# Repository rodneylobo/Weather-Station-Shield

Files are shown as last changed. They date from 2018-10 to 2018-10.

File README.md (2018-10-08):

# Weather-Station-Shield
This Arduino Nano shield was used in developing Weather Stations
It used  Humidity sensor, Carbon dioxide sensor, Light intensity sensor (photoresistor), Air Pressure sensor and Temperature sensor.
All of these can be displayed using the LCD
It also uses a bluetooth to wirelessely send the collected data to cell phones.
All that needs to be done is etch the pcb, and solder appropriate components.
Components required:
  1. FR1 boards (FR4 are better, actually)
  2. Female Header pins
  3. 16X2 LCD
  4. Trimpot (103 or above)
  5. 2.5 mm DC female jack
  6. Resistors (x3)
  7. 3mm LED (x2)
  8. Arduino Nano
  9. Photoresistor
  10. DHT11 (humidity sensor)
  11. BMP180 (air pressure sensor)
  12. MQ135 (carbon dioxide/ Air Quality sensor)
  13. LM35 (temperature sensor)
  14. Bluetooth module (HC05 or HC06)
  15. 9V battery and battery connector
  16. 2.5mm male DC jack
  17. Single strand wires
  18. Solder and soldering iron

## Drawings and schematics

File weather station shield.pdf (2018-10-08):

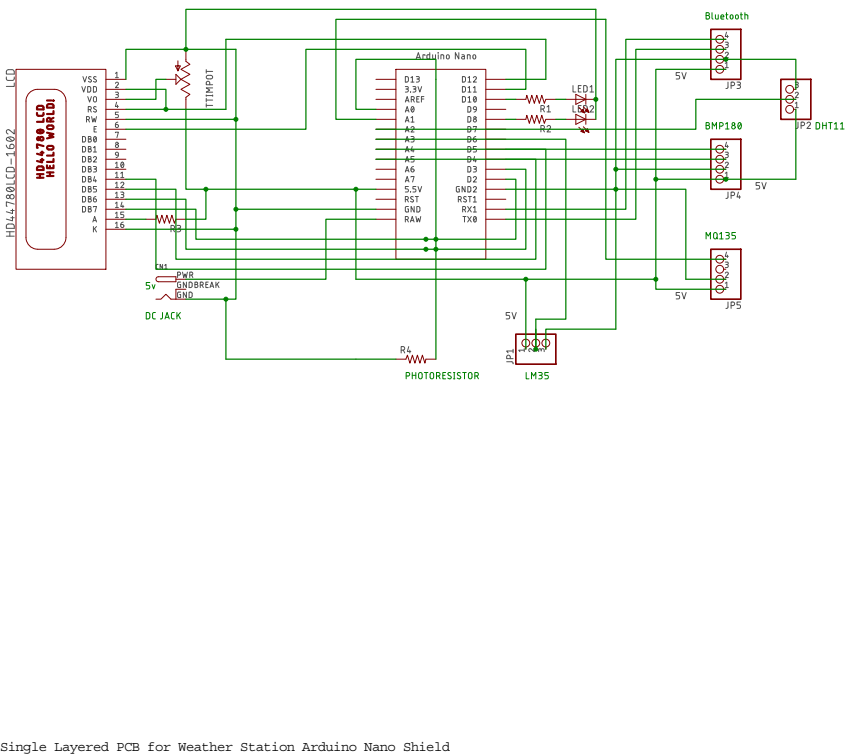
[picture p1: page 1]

Single Layered PCB for Weather Station Arduino Nano Shield

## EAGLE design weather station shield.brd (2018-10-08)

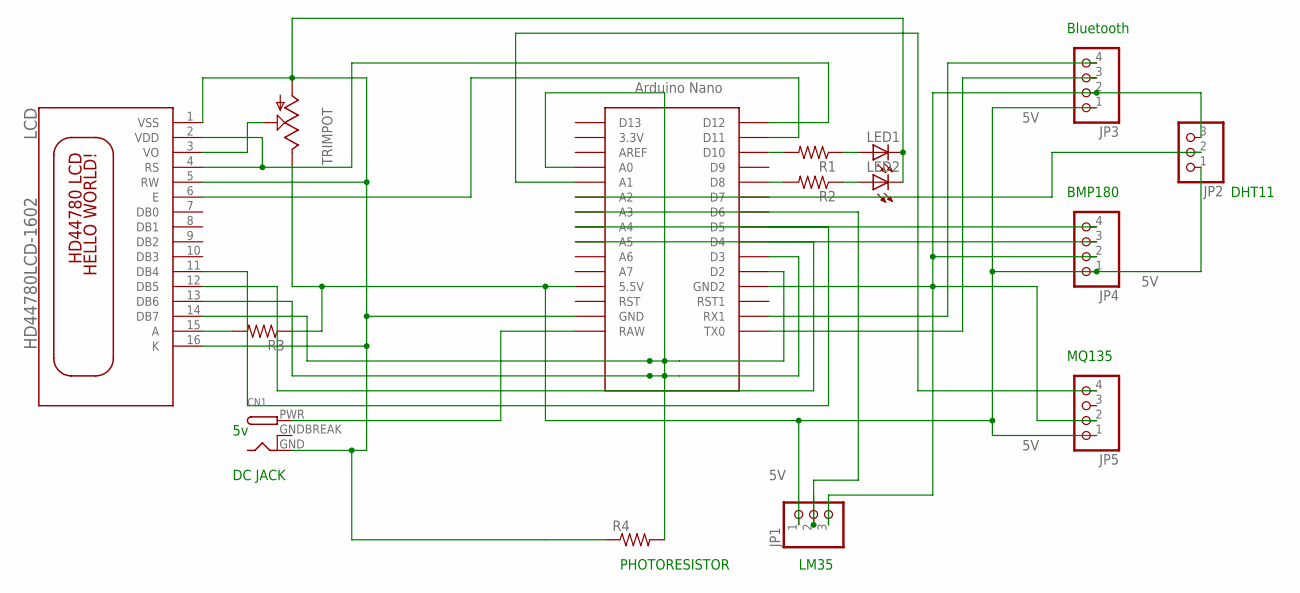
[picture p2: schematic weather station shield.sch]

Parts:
CN1: DCBARRELPTH; DCJACK_2MM_PTH
JP1, JP2: PINHD-1X3; 1X03
JP3, JP4, JP5: PINHD-1X4; 1X04
LCD: HD44780LCD-1602; LCD1602
LED1, LED2: LED5MM
R1, R2, R3, R4: R-US_0204/7; 0204/7
TRIMPOT: TRIM_US-CA6V; CA6V
U$1: NANO

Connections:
5V: JP1.1, JP2.1, JP3.1, JP4.1, JP5.1, R3.1, TRIMPOT.E, U$1.5V (5.5V)
GNDBREAK: CN1.GNDBREAK
unnamed: LCD.13 (DB6), U$1.D3, U$1.ICSP1, U$1.ICSP3, U$1.ICSP5
unnamed: LCD.12 (DB5), U$1.D4
unnamed: LCD.3 (VO), TRIMPOT.S
unnamed: JP2.2, U$1.A2
unnamed: LCD.6 (E), U$1.D11
unnamed: LCD.15 (A), R3.2
unnamed: LCD.11 (DB4), U$1.D5
unnamed: JP3.4, U$1.RX1
unnamed: JP3.3, U$1.TX0
unnamed: JP4.4, U$1.A4
unnamed: JP4.3, U$1.A5
unnamed: R1.2, U$1.D10
unnamed: LED1.A, R1.1
unnamed: R2.2, U$1.D8
unnamed: LED2.A, R2.1
unnamed: R4.2, U$1.A0
unnamed: JP1.3, JP2.3, JP3.2, JP4.2, JP5.2, U$1.GND1 (GND2)
unnamed: JP5.4, U$1.A1
unnamed: LCD.14 (DB7), U$1.D2, U$1.ICSP2, U$1.ICSP4, U$1.ICSP6
unnamed: JP1.2, U$1.A3
unnamed: CN1.PWR, U$1.RAW
VDD: LCD.2 (VDD), LCD.4 (RS), U$1.D12
VSS: CN1.GND, LCD.1 (VSS), LCD.5 (RW), LCD.16 (K), LED1.K (C), LED2.K (C), R4.1, TRIMPOT.A, U$1.GND

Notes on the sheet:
Bluetooth
BMP180
MQ135
DHT11
LM35
PHOTORESISTOR
DC JACK

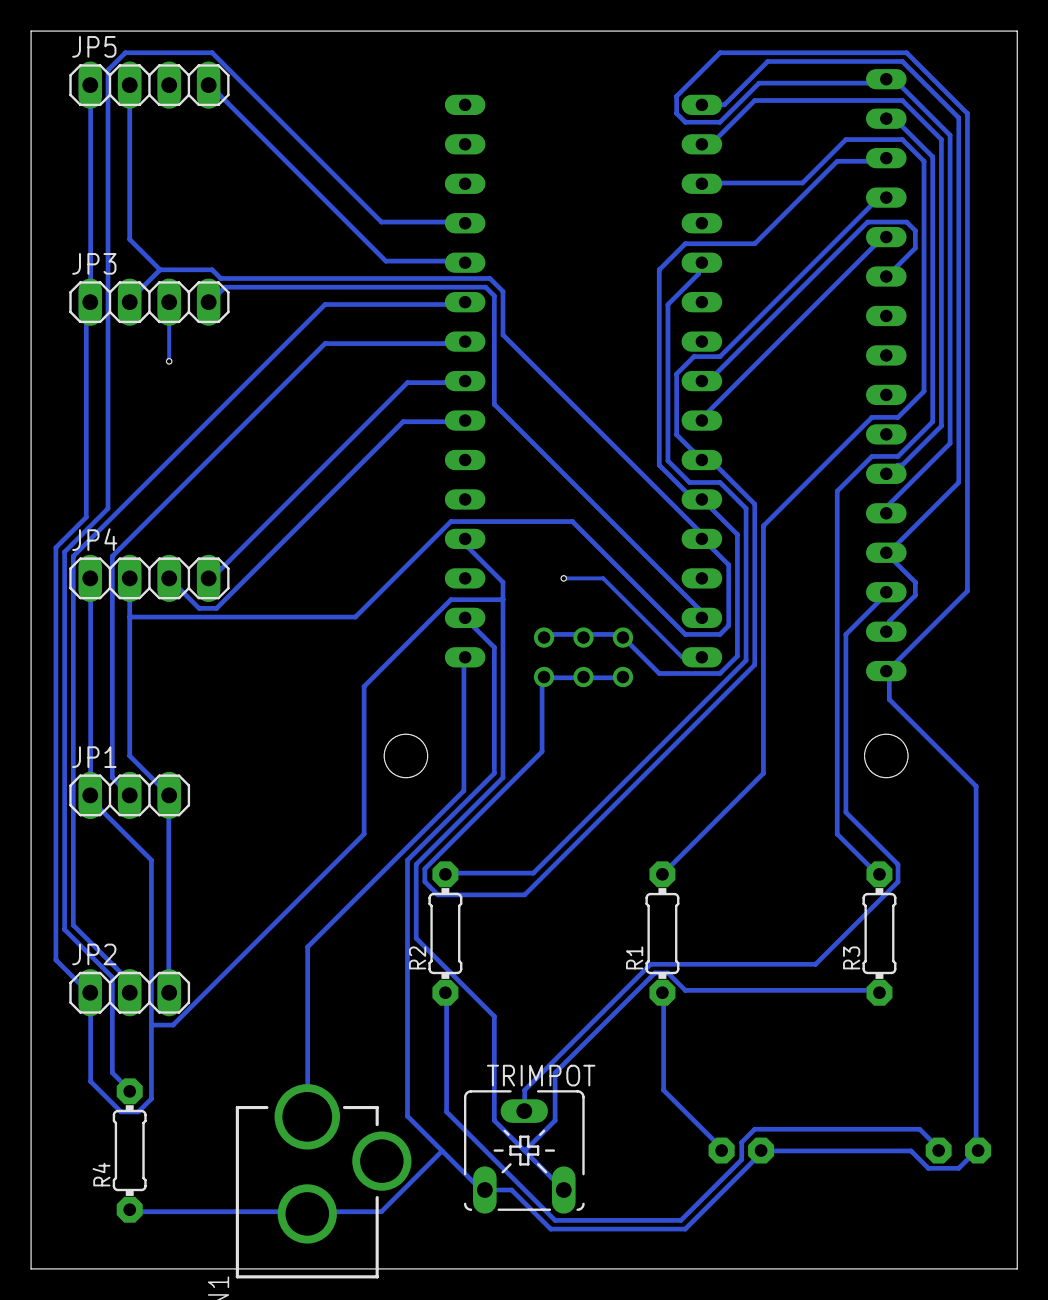
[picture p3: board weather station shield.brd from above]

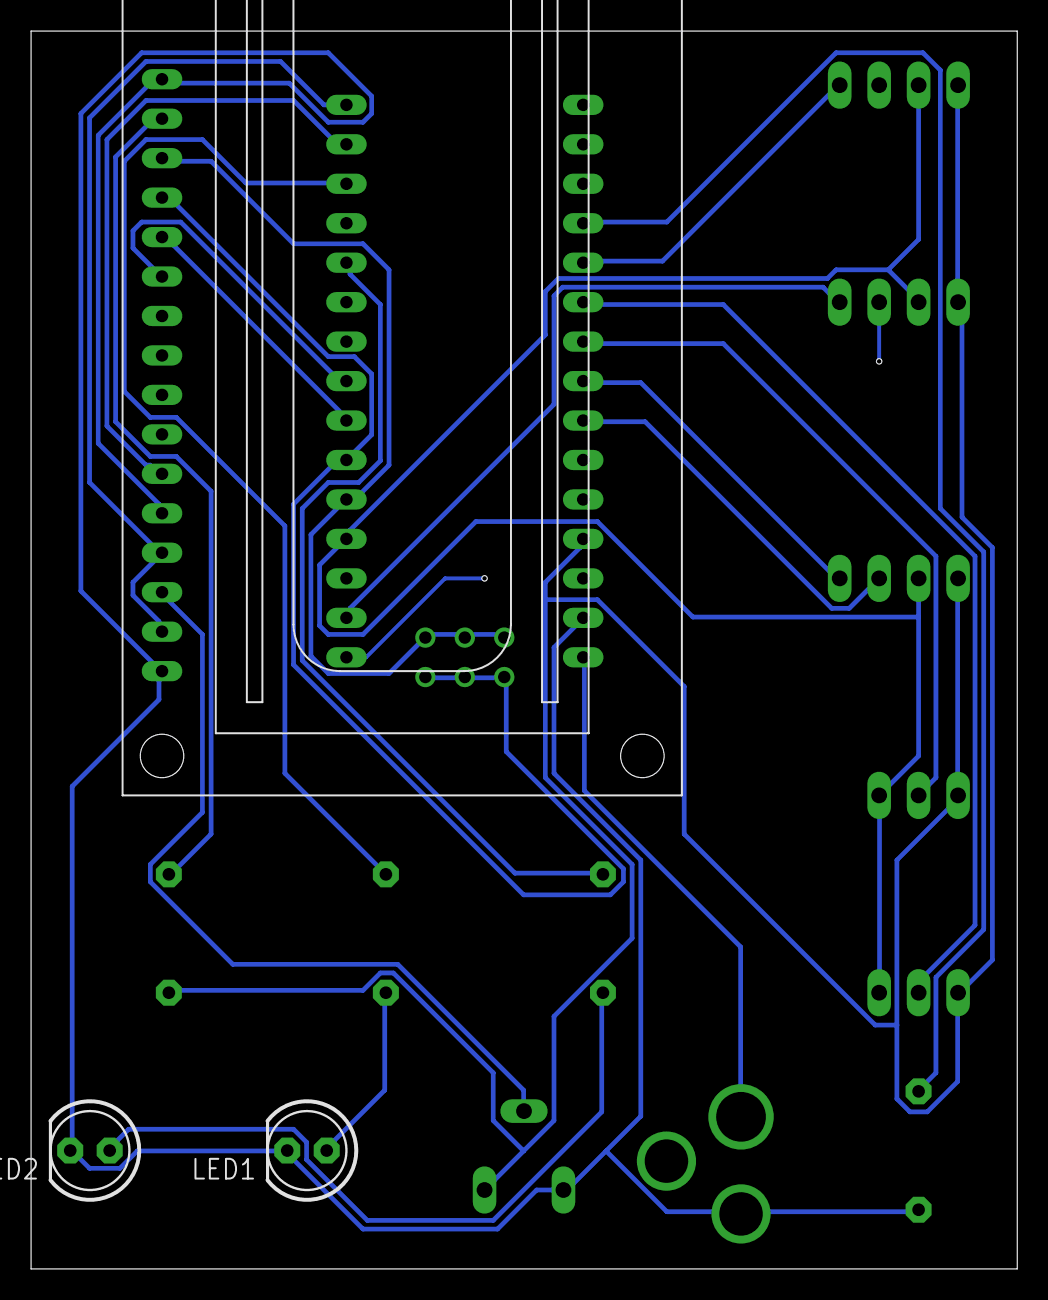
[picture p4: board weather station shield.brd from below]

Board: 2 copper layers, 63.5 x 79.7 mm, 15 parts (3 on the bottom side), 24 nets.

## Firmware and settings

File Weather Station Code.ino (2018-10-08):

#include <Wire.h>
#include <Adafruit_BMP085.h>
#include <VirtualWire.h>
#include <dht.h>
#include <LiquidCrystal.h>


Adafruit_BMP085 bmp;
dht DHT;

#define DHT11_PIN   A2                        //A2 will read the humidity

#define co2_ip     A1                        //analog feed from MQ135
                 //digital feed from MQ135
#define co2_0      55                        //calibrated CO2 0 level. This needs to be changed according to the value of the place you are using the CO2 sensor
   
int tx_no=0;                                 // Transmission # for testing



// initialize the library by associating any needed LCD interface pin
// with the arduino pin number it is connected to
const int rs = 12, en = 11, d4 = 5, d5 = 4, d6 = 3, d7 = 2;
LiquidCrystal lcd(rs, en, d4, d5, d6, d7);

  
void setup() {
    Serial.begin(9600);
    Serial.println("setup");
    digitalWrite(10,LOW);
    
    pinMode(DHT11_PIN, INPUT);

    pinMode(7, OUTPUT);
    pinMode(co2_ip,INPUT);                     //MQ135 analog feed set for input
    
   

    bmp.begin();

    
    // Initialise the IO and ISR
    vw_set_tx_pin(7);
    vw_set_ptt_inverted(true); // Required for DR3100
    vw_setup(2000);  // Bits per sec
    
    lcd.begin(16, 2);

    
    
  

}
  
void loop() {

  /*Initial setup for gas sensor.. this is long...*/ 
     
     int co2_now[10];                               //int array for co2 readings
     int co2_raw = 0;                               //int for raw value of co2
     int co2_comp = 0;                              //int for compensated co2 
     int co2_ppm = 0;                               //int for calculated ppm
     int co2_avg = 0;                               //int for averaging

    for (int x = 0;x<10;x++)                        //samplpe co2 10x over 0.5 seconds
        {                   
         co2_now[x]=analogRead(A1);
         delay(50);
        }

     for (int x = 0;x<10;x++)
        {                     //add samples together
          co2_avg=co2_avg + co2_now[x];
    
        }

     co2_raw = co2_avg/10;                           //divide samples by 10
     co2_comp = co2_raw - co2_0;                     //get compensated value
     co2_ppm = map(co2_comp,0,1023,400,5000);        // 0 is mapped to the average CO2 levels of Earth i.e., 400 ppm AND 1023 is mapped to 5000 ppm. The 5000 ppm is chosen arbitrarily just for lulz.

    /* reading CO2 Level ends now, and reading values of other sensors begins*/

    float temperature = bmp.readTemperature();       // reading temperature
    
    long pressure = bmp.readPressure();              // reading pressure
    
    DHT.read11(DHT11_PIN);                           // reading humidity

    /* Code for all transmitted values begins now*/

    /*Transmitting the numver of values read*/

    String value0 = "-------- This is Reading# " + String(tx_no) + " --------";

    char *msg = value0.c_str();
  
    digitalWrite(13, true); // Flash a light to show transmitting
    vw_send(msg, strlen(msg));
    vw_wait_tx(); // Wait until the whole message is gone
    digitalWrite(13, false);
    
    /*Transmitting Temperature*/

    String value1 = " : Temperature = " + String(temperature) + " *C";  //displaying temperature as Temperature = [Temperature Value] *C

    msg = value1.c_str();
  
    digitalWrite(13, true); // Flash a light to show transmitting
    vw_send(msg, strlen(msg));
    vw_wait_tx(); // Wait until the whole message is gone
    digitalWrite(13, false);

    /*Transmitting Pressure*/

    String value2 = "Pressure = " + String(pressure) + " Pa"; //displaying Pressure as Pressure = [Pressure Value] Pa
    
    msg = value2.c_str();
    
    digitalWrite(13, true); // Flash a light to show transmitting
    vw_send(msg, strlen(msg));
    vw_wait_tx(); // Wait until the whole message is gone
    digitalWrite(13, false);


    /*Transmitting relative Humidity*/

    String value3 = "Humidity = " + String(DHT.humidity) + " %rH"; //displaying Humidity as Humidity = [Humidity Value] %rH

    msg = value3.c_str();
  
    digitalWrite(13, true); // Flash a light to show transmitting
    vw_send(msg, strlen(msg));
    vw_wait_tx(); // Wait until the whole message is gone
    digitalWrite(13, false);


    /*Transmitting CO2 Level*/

    String value4 = "CO2 Level = " + String(co2_ppm) + " ppm"; //displaying CO2 Level as CO2 Level = [CO2 Level Value] ppm

    msg = value4.c_str();
  
    digitalWrite(13, true); // Flash a light to show transmitting
    vw_send(msg, strlen(msg));
    vw_wait_tx(); // Wait until the whole message is gone
    digitalWrite(13, false);

    /*Updating Transmission values*/

    tx_no++;                                // Update transmission number after every loop
    

    /*Codes for Transmission ends and codes for LCD display begins*/
    
    
    /* Code for Temperature display begins from here. Do not copy this part for other sensors*/

    lcd.setCursor(0, 0); //set cursor to initial position
   
    lcd.print("Temp = ");
    lcd.print(temperature);
    lcd.print(" *C");
    
    
    /* Code for Pressure display begins from here. You copy this part for other sensors but be careful about the LCD cursor position, pins and inputs*/

    lcd.setCursor(0, 1);

    lcd.print("Pre = ");
    lcd.print(pressure);
    lcd.print(" Pa");

     
    /*Observer can read the values within the delay below, and after that LCD clears to show more sensor values*/
    
    delay (1500);
    lcd.clear();

    /* Code for Humidity sensor begins from here. You copy this part for other sensors but be careful about the LCD cursor position, pins and inputs*/
    
    lcd.setCursor(0, 0);

    lcd.print("Hum = ");
    lcd.print(DHT.humidity);
    lcd.print(" %rH");


    /* Code for CO2 levels begins from here. You copy this part for other sensors but be careful about the LCD cursor position, pins and inputs*/
    
    lcd.setCursor(0,1);

    lcd.print("CO2 = ");
    lcd.print(co2_ppm);
    lcd.print(" ppm");


    
    /*Observer can read the values within the delay below, and after that LCD clears*/

    delay(1500);
    
  
}

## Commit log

2018-10-08 Add files via upload
    Project files and pdf added
    [weather station shield.brd, weather station shield.sch]
2018-10-08 Add files via upload
    Arduino sketch added
